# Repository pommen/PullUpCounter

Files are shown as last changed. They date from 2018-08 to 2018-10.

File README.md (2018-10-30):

# PullupCounter
Simple counter that keeps track of how many pullups that has been done in a day and displays it on a double led array display.
Resets every day and only lights up during office hours. Time keeping is done with a DS1307 RTC.
Manually changeable pullups counts with a encoder, to "cheat" or correct the amount of reps that has been done.
Based on a ATMEGA328p MCU (5V16MHZ) running Arduino code.

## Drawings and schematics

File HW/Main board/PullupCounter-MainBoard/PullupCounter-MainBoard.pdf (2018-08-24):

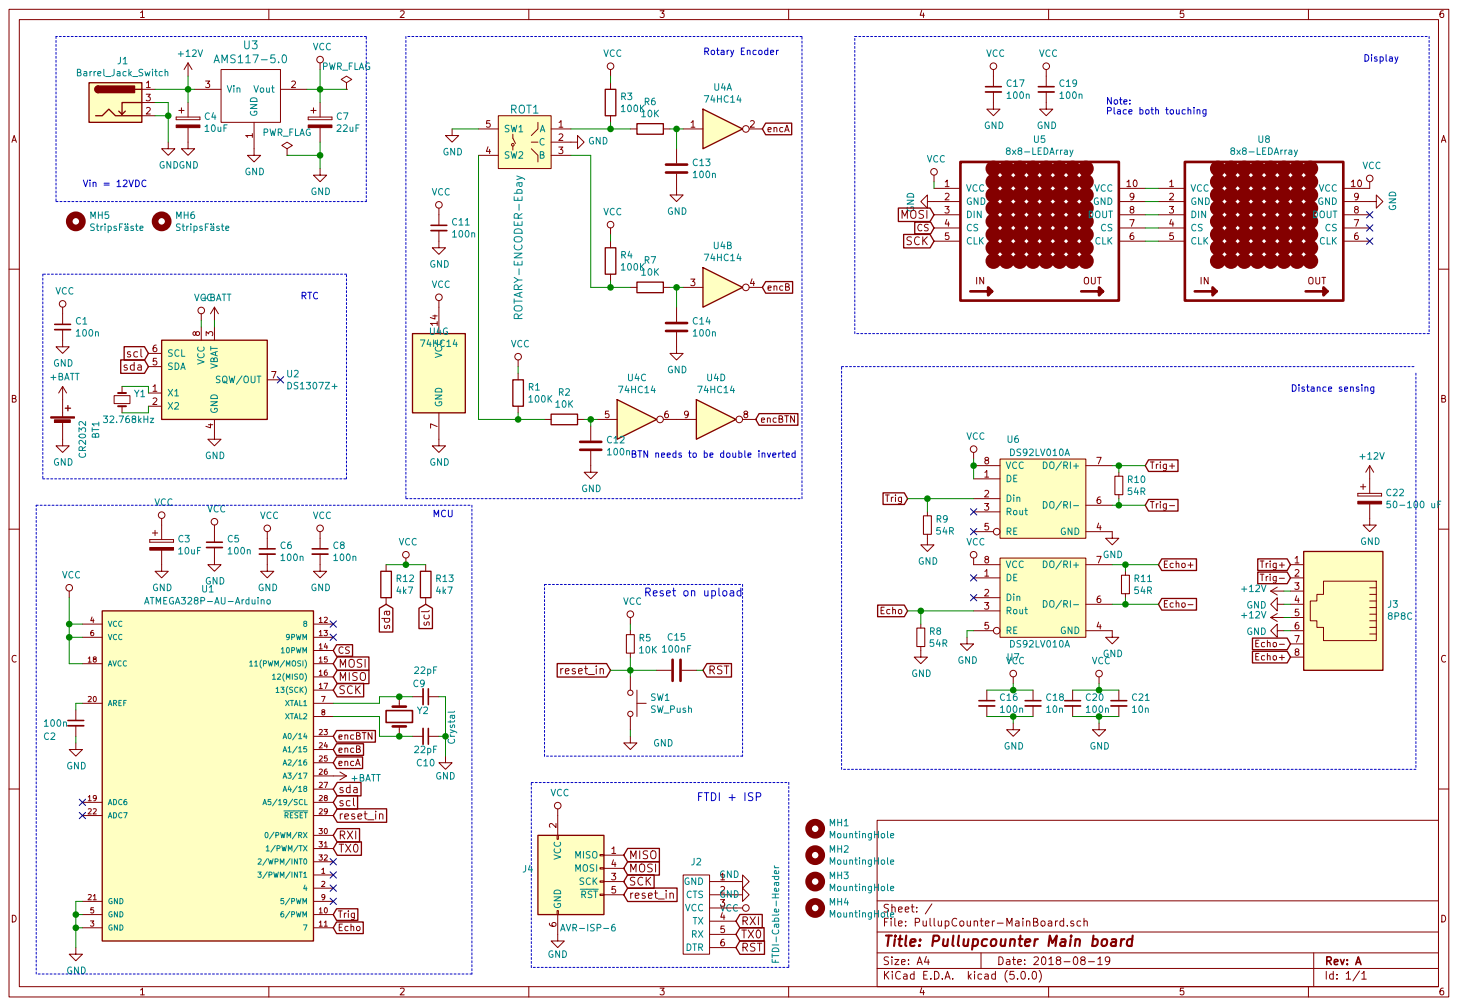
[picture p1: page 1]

4 SDA 5 SCL 6 SQW/OUT 7 VCC

Trig Echo

2 SCK 3 MOSI 4 RST 5 GND

Id: 1/1 Title: Pullupcounter Main board

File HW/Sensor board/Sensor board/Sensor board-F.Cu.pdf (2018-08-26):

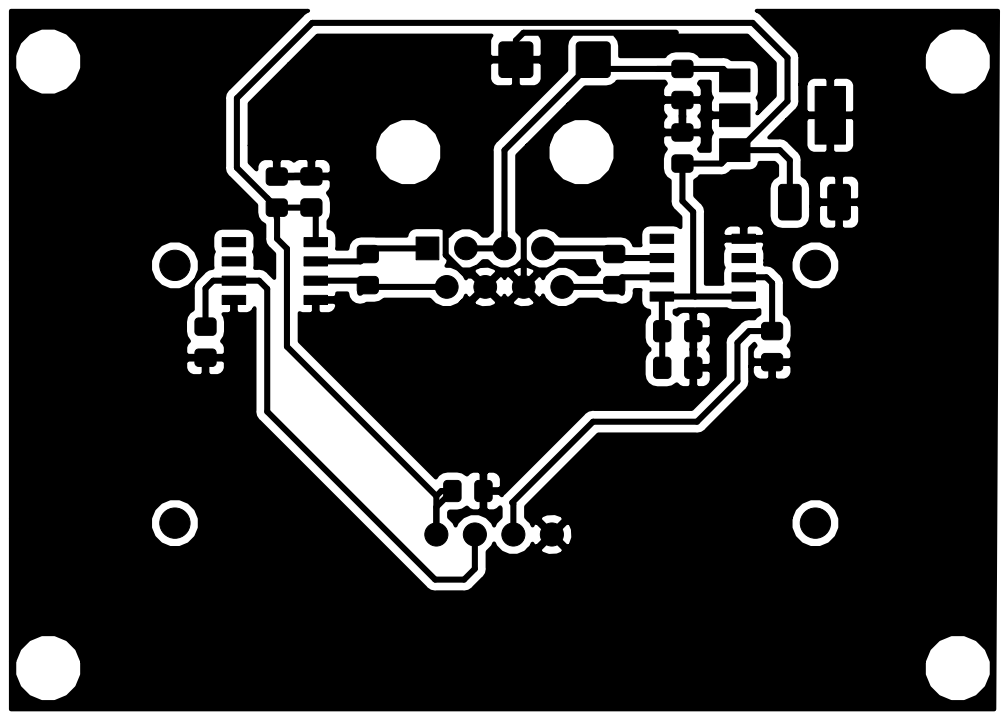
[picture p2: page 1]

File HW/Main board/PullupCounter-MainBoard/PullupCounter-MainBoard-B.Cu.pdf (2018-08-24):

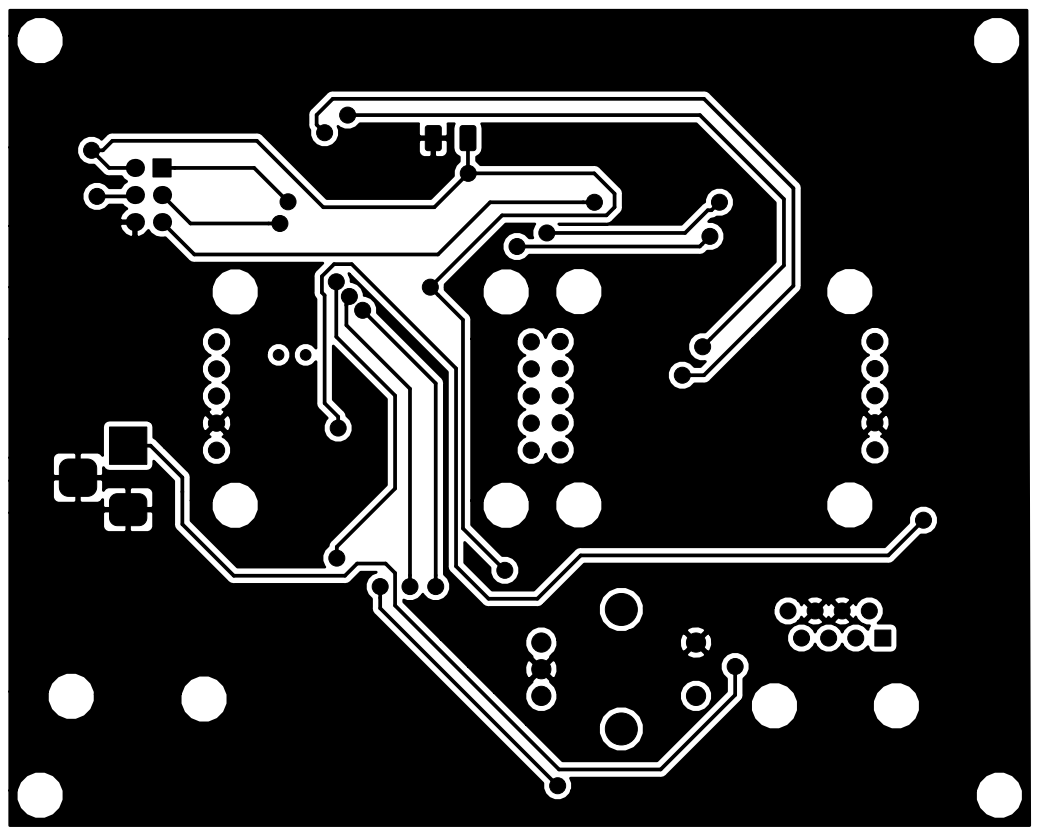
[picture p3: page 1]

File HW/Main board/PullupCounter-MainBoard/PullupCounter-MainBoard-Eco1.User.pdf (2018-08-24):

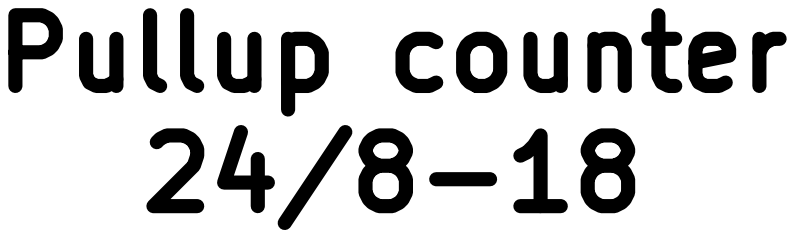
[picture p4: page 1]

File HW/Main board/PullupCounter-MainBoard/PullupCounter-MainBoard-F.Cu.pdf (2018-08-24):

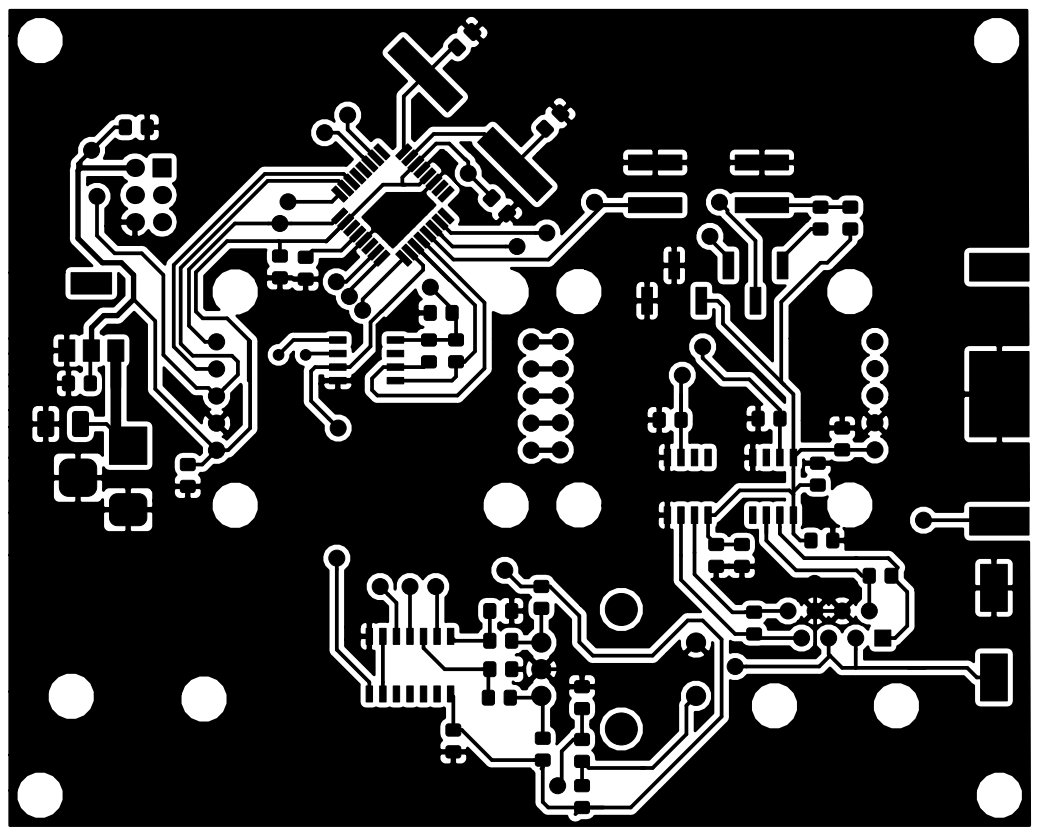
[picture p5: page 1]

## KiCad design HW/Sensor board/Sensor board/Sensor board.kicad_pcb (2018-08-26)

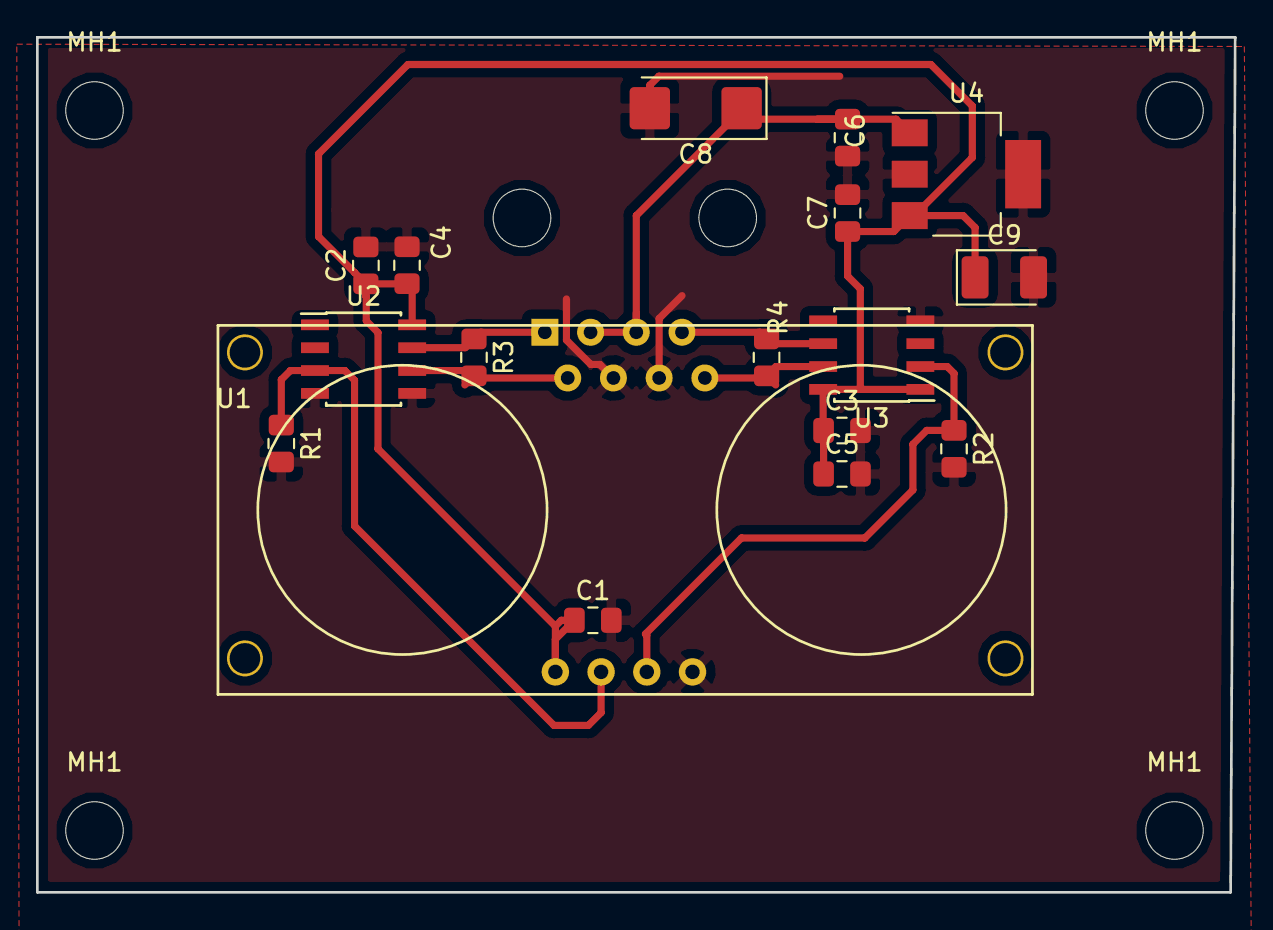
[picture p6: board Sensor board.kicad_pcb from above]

Board: 2 copper layers, 66.5 x 47.5 mm, 22 parts (1 on the bottom side), 9 nets.

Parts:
C1, C2, C3, C6: 100n; C_0805_2012Metric_Pad1.15x1.40mm_HandSolder
C4, C5: 10n; C_0805_2012Metric_Pad1.15x1.40mm_HandSolder
C7: 1u; C_0805_2012Metric_Pad1.15x1.40mm_HandSolder
C8: 15u; CP_EIA-6032-20_AVX-F_Pad2.25x2.35mm_HandSolder
C9: 15u; CP_EIA-3528-12_Kemet-T_Pad1.50x2.35mm_HandSolder
J1: 8P8C; RJ45_Amphenol_54602-x08_Horizontal
MH1, MH1#2, MH1#3, MH1#4: MountingHole; MountingHole_3.2mm_M3_DIN965
R1, R2, R3, R4: 54R; R_0805_2012Metric_Pad1.15x1.40mm_HandSolder
U1: Hc-SR04; HC-SR04
U2, U3: DS92LV010A; SOIC-8_3.9x4.9mm_P1.27mm
U4: LM2937xMP; SOT-223-3_TabPin2

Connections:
+12V: C6.1, C8.1, J1.3, J1.5, U4.1
ECHO: R2.1, U1.3, U3.2
ECHO+: J1.8, R4.1, U3.7
ECHO-: J1.7, R4.2, U3.6
GND: C1.2, C2.2, C3.2, C4.2, C5.2, C6.2, C7.2, C8.2, C9.2, J1.4, J1.6, R1.2, R2.2, U1.4, U2.4, U2.5, U3.4, U4.2
TRIG: R1.1, U1.2, U2.3
TRIG+: J1.1, R3.1, U2.7
TRIG-: J1.2, R3.2, U2.6
VCC: C1.1, C2.1, C3.1, C4.1, C5.1, C7.1, C9.1, U1.1, U2.8, U3.1, U3.8, U4.3

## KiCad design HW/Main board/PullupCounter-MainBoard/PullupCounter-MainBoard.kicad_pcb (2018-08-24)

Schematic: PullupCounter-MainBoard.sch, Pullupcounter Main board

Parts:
BT1: CR2032; BatteryHolder_MPD_BC2003_1x2032
C1, C2, C5, C6, C8, C11, C12, C13, C14, C16, C17, C19, C20: 100n; C_0805_2012Metric_Pad1.15x1.40mm_HandSolder
C3, C4: 10uF; CP_EIA-3528-12_Kemet-T_Pad1.50x2.35mm_HandSolder
C7: 22uF; C_0805_2012Metric_Pad1.15x1.40mm_HandSolder
C9, C10: 22pF; C_0805_2012Metric_Pad1.15x1.40mm_HandSolder
C15: 100nF; C_0805_2012Metric_Pad1.15x1.40mm_HandSolder
C18, C21: 10n; C_0805_2012Metric_Pad1.15x1.40mm_HandSolder
C22: 50-100 uF; CP_Elec_10x10.5
J1: Barrel_Jack_Switch; BarrelJack_Horizontal
J2: FTDI-Cable-Header; PinHeader_1x06_P2.54mm_Vertical_SMD_Pin1Left
J3: 8P8C; RJ45_Amphenol_54602-x08_Horizontal
J4: AVR-ISP-6; PinSocket_2x03_P2.54mm_Vertical
MH1, MH2, MH3, MH4: MountingHole; MountingHole_3.2mm_M3
MH5, MH6: StripsFäste; MountingHole_3.2mm_M3
R1, R3, R4: 100K; R_0805_2012Metric_Pad1.15x1.40mm_HandSolder
R2, R5, R6, R7: 10K; R_0805_2012Metric_Pad1.15x1.40mm_HandSolder
R8, R9, R10, R11: 54R; R_0805_2012Metric_Pad1.15x1.40mm_HandSolder
R12, R13: 4k7; R_0805_2012Metric_Pad1.15x1.40mm_HandSolder
ROT1: ROTARY-ENCODER-Ebay
SW1: SW_Push; PushBTN KSC241G
U1: ATMEGA328P-AU-Arduino; TQFP-32_7x7mm_P0.8mm
U2: DS1307Z+; SOIC-8_3.9x4.9mm_P1.27mm
U3: AMS117-5.0; SOT-223
U4: 74HC14; SOIC-14_3.9x8.7mm_P1.27mm
U5, U8: 8x8-LEDArray; 8x8LEDArray
U6, U7: DS92LV010A; SOIC-8_3.9x4.9mm_P1.27mm
Y1: 32.768kHz; Crystal_AT310_D3.0mm_L10.0mm_Horizontal
Y2: Crystal; Crystal_SMD_HC49-SD_HandSoldering

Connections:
+12V: C4.1, C22.1, J1.1, J3.3, J3.5, U3.3
+BATT: BT1.1, U1.26, U2.3
CS: U1.14, U5.4
Echo: R8.1, U1.11, U7.3
Echo+: J3.8, R11.1, U7.7
Echo-: J3.7, R11.2, U7.6
GND: BT1.2, C1.2, C2.2, C3.2, C4.2, C5.2, C6.2, C7.2, C8.2, C9.1, C10.1, C11.2, C12.2, C13.2, C14.2, C16.2, C17.2, C18.2, C19.2, C20.2, C21.2, C22.2, J1.2, J1.3, J2.1, J2.2, J3.4, J3.6, J4.6, R8.2, R9.2, ROT1.2, ROT1.5, SW1.2, U1.3, U1.5, U1.21, U2.4, U3.1, U4.7 (GND), U5.2, U6.4, U7.4, U7.5, U8.9
MISO: J4.1, U1.16
MOSI: J4.4, U1.15, U5.3
unnamed: C2.1, U1.20
unnamed: C9.2, U1.7, Y2.1
unnamed: C10.2, U1.8, Y2.2
unnamed: C12.1, R2.1, U4.5
unnamed: C13.1, R6.1, U4.1
unnamed: C14.1, R7.1, U4.3
unnamed: R1.2, R2.2, ROT1.4
unnamed: R3.2, R6.2, ROT1.1
unnamed: R4.2, R7.2, ROT1.3
unnamed: U2.1, Y1.1
unnamed: U2.2, Y1.2
unnamed: U4.6, U4.9
unnamed: U5.6, U8.5
unnamed: U5.7, U8.4
unnamed: U5.8, U8.3
unnamed: U5.9, U8.2
unnamed: U5.10, U8.1
RST: C15.1, J2.6
RXI: J2.4, U1.30
SCK: J4.3, U1.17, U5.5
TX0: J2.5, U1.31
Trig: R9.1, U1.10, U6.2
Trig+: J3.1, R10.1, U6.7
Trig-: J3.2, R10.2, U6.6
VCC: C1.1, C3.1, C5.1, C6.1, C7.1, C8.1, C11.1, C16.1, C17.1, C18.1, C19.1, C20.1, C21.1, J2.3, J4.2, R1.1, R3.1, R4.1, R5.1, R12.1, R13.1, U1.4, U1.6, U1.18, U2.8, U3.2, U4.14 (VCC), U5.1, U6.1, U6.8, U7.8, U8.10
encA: U1.25, U4.2
encB: U1.24, U4.4
encBTN: U1.23, U4.8
reset_in: C15.2, J4.5, R5.2, SW1.1, U1.29
scl: R13.2, U1.28, U2.6
sda: R12.2, U1.27, U2.5

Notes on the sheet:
FTDI + ISP
Reset on upload
Note: Place both touching
Display
Distance sensing
Vin = 12VDC
RTC
MCU
Rotary Encoder
BTN needs to be double inverted

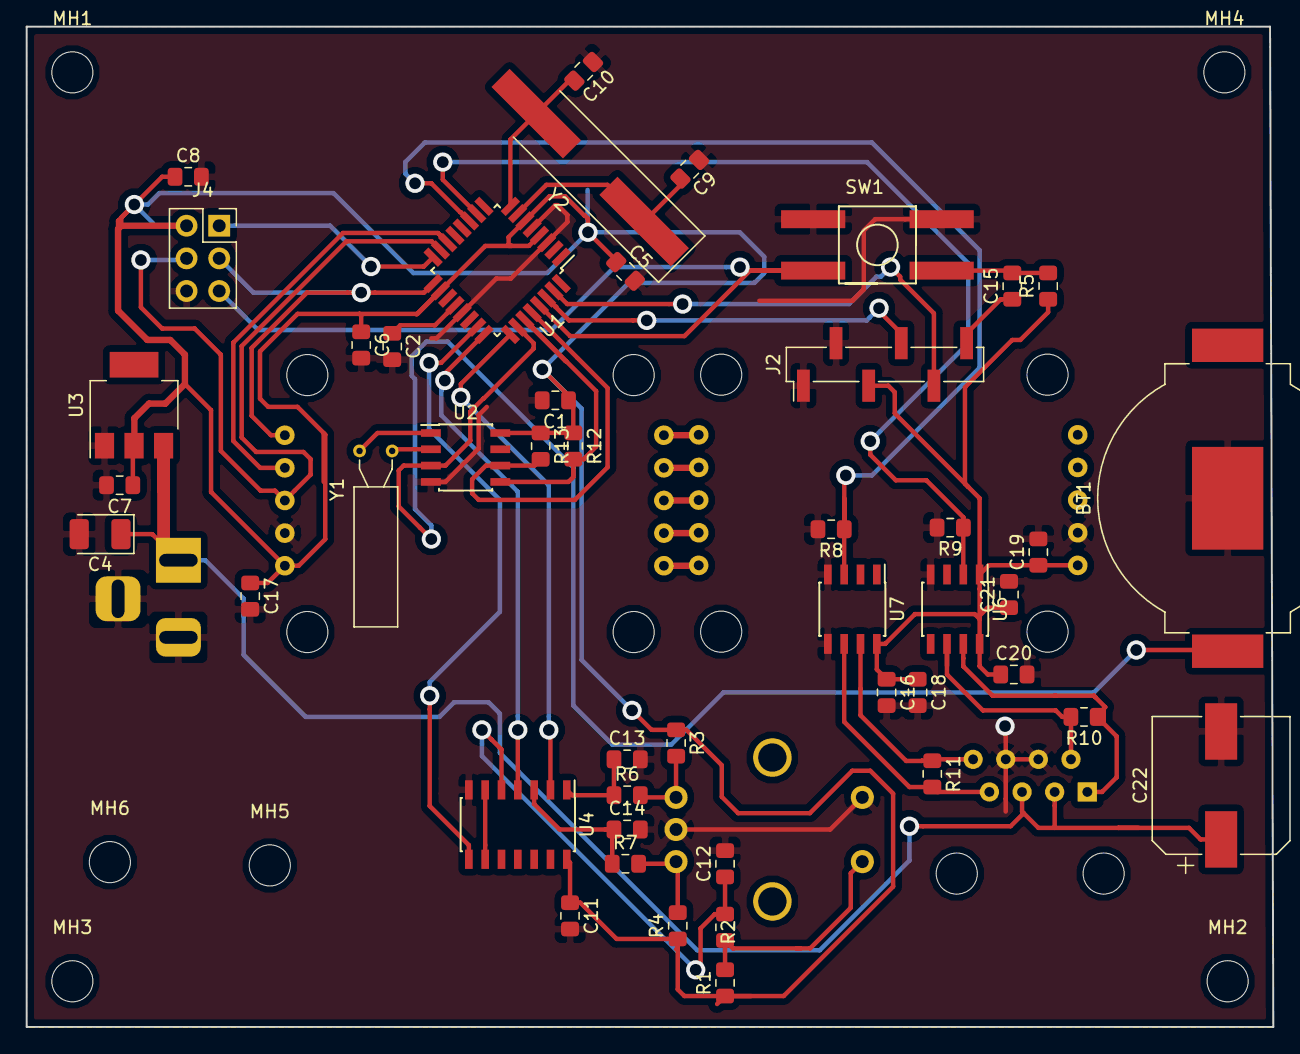
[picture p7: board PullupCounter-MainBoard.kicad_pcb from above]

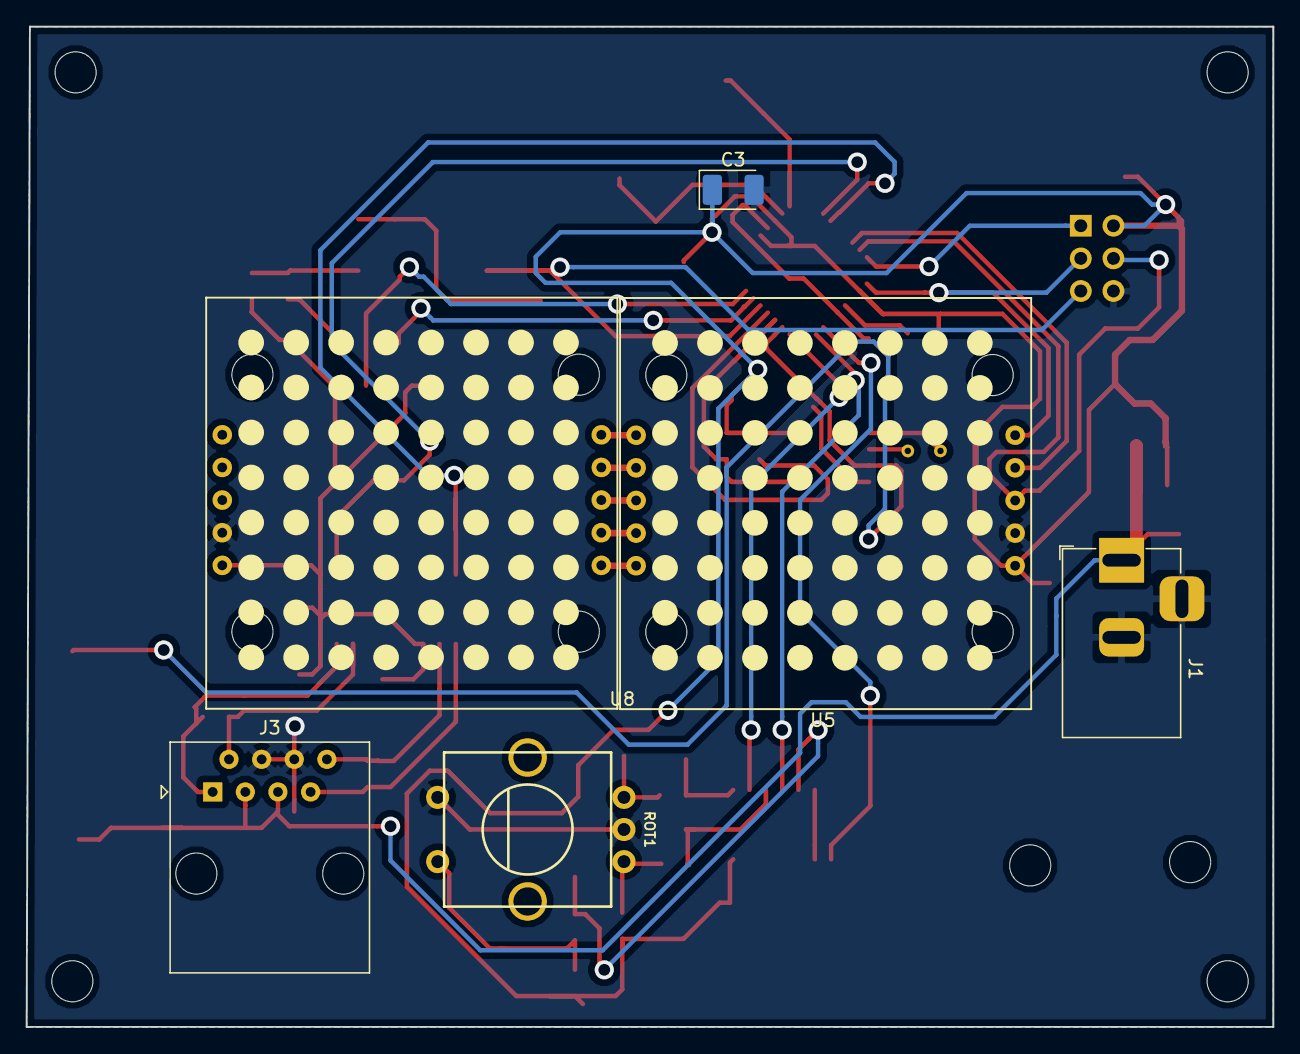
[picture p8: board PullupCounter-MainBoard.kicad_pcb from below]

Board: 2 copper layers, 97.0 x 77.9 mm, 58 parts (6 on the bottom side), 40 nets.

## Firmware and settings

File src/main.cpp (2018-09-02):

/*
Pullup counter till Arnfinn

Maybe to be in 2.0: 

Settings:
      Distance to be a pullup, like a motivational up arrow, or something
      Brightness 0-15
      Time - need more ledarrays to display properly

todo:
Firmware 1.0 done.


*/

#include <Arduino.h>
#include <SPI.h>
#include <bitBangedSPI.h>
#include <MAX7219_Dot_Matrix.h>
#include <ClickEncoder.h>
#include <TimerOne.h>
#include <Wire.h>
#include "RTClib.h"
#include <EEPROM.h>
#include <UltraDistSensor.h>

//**************************

#define DEBUG

//**************************
void setBrightness();
void timerIsr();
void btnstate();
void setCompileTime();
void updateDisplay();
void showTime();
void pulsingHearts();
void Scollingtext();
int16_t oldEncPos, encPos;
uint8_t buttonState;
uint8_t daylightAddr = 0;
bool newNumer = 0;
bool done = 0;
int numPullups = 0;
int oldNumPullups = 0;
char message[] = {};
int lastDay = 0;
int temp = 0;
bool LEDOff = 0;
unsigned long pullUpTime = 0;
unsigned long pullUpHELDTime = 0;
unsigned long hasGoneDownTime = 0;
bool hasGoneDown = 0;
uint16_t rangeUpdateTimer = 0;
uint16_t clockUpdateTimer = 0;
int daylight = 8;
#define pinA A1
#define pinB A2
#define pinSw A0 //switch on enc
#define STEPS 4
char daysOfTheWeek[7][12] = {"Sunday", "Monday", "Tuesday", "Wednesday", "Thursday", "Friday", "Saturday"};
unsigned long lastMoved = 0;
uint8_t MOVE_INTERVAL = 40; // mS
int messageOffset;
int scollingMessageOffset;
const byte chips = 2;
float distanceReading = 0.00;
bool doneWithScolling = 0;

UltraDistSensor mysensor;
RTC_DS1307 rtc;
ClickEncoder encoder(pinA, pinB, pinSw, STEPS);
DateTime now;
// 2 chips (display modules), hardware SPI with load on D10
MAX7219_Dot_Matrix display(chips, 10); // Chips / LOAD

void setup()
{
      Serial.begin(9600);
      display.begin();
      Timer1.initialize(1000);
      Timer1.attachInterrupt(timerIsr);

      encoder.setAccelerationEnabled(false);
      if (!rtc.begin())
      {
            Serial.println("Couldn't find RTC");
      }
      mysensor.attach(6, 7); //Trigger pin , Echo pin
      oldEncPos = 0;
      daylight = EEPROM.get(daylightAddr, daylight);
      Serial.print("Brightness : ");
      Serial.println(daylight);
      if (daylight > 15 || daylight < 0)
      {
            daylight = 8;
      }

      display.setIntensity(daylight);

      setCompileTime();
      //showTime();

      pulsingHearts();
}

void loop()
{
      //update things:

      encPos += encoder.getValue(); //check if the encoder has changed

      if (millis() - clockUpdateTimer >= 30000) //read clock every 30 seconds
      {
            now = rtc.now();
            // Serial.print(now.second(), DEC);					
      }

      if (millis() - rangeUpdateTimer >= 100)
      {
            distanceReading = mysensor.distanceInCm();
            rangeUpdateTimer = millis();
      }

      //***********

   /*    
      Serial.print("Sensor Reading :");
      Serial.print(distanceReading);
      Serial.println(" CM");  */
      

      if (distanceReading > 10.00)
      {
            pullUpTime = millis();
      }
      //else
      // Serial.println(millis() - pullUpTime);

      if (millis() - pullUpTime > 500 && hasGoneDown == 1)
      {
            // pullUpTime = millis();
            Serial.print("Sensor Reading :");
            Serial.print(distanceReading);
            Serial.println(" CM");
            numPullups++;
            hasGoneDown = 0;
      }

      if (distanceReading > 30.00)
      {
            hasGoneDown = 1;
      }

      //has the encoder value changed?
      if (encPos != oldEncPos)
      {
            // Serial.print("Encoder Value: ");
            // Serial.println(encPos);
            int diff = encPos - oldEncPos;
            numPullups = numPullups + diff;
            oldEncPos = encPos;

            //need this here because of some bug... Yuck!
            Serial.print("now.dayOfTheWeek() : ");
            Serial.println(now.dayOfTheWeek());
            Serial.print("lastDay: ");
            Serial.println(lastDay);
      }

      //never under 0 pullups!
      if (numPullups < 0)
      {
            numPullups = 0;
            oldNumPullups = 0;
      }

      //Is there a new number to display?
      if (numPullups != oldNumPullups)
      {
            newNumer = 1;
            oldNumPullups = numPullups;
            done = 0;
            Serial.println(numPullups);
      }
      else
            newNumer = 0;

      // update display if time is time to
      if (millis() - lastMoved >= MOVE_INTERVAL)
      {
            updateDisplay();
            lastMoved = millis();
      }

      //Check the encoder button state (with state machine)
      // btnstate();

      if (lastDay != now.dayOfTheWeek())
      {
            lastDay = now.dayOfTheWeek();
            numPullups = 0;
            oldNumPullups = 0;
            temp = lastDay;
            Serial.println("Resetting due to New day!");
            Serial.print("now.dayOfTheWeek() : ");
            Serial.println(now.dayOfTheWeek());
            Serial.print("lastDay: ");
            Serial.println(lastDay);
      }

      //Turn off the LED's at 'out of office hours'
      if (!LEDOff)
      {
            if (now.hour() < 6 || now.hour() > 18)
            {

#ifndef DEBUG

                  display.end();
                  LEDOff = 1;
#else
                  display.setIntensity(0);
                  LEDOff = 1;

#endif // DEBUG
            }
            else
            {
                  display.setIntensity(daylight);
                  LEDOff = 0;
            }
      }

      btnstate(); //have we pressed the encoder button?

} // end of loop

void updateDisplay()
{
      itoa(numPullups, message, 10); //int to string

      if (done)
      {
            display.sendString(message);
      }
      else
      {
           /*  Serial.print("messageOffset: ");

            Serial.println(messageOffset); */
            display.sendSmooth(message, messageOffset);
            // next time show one pixel onwards
            if (messageOffset++ >= (int)(strlen(message) * 8))
            { //if we have run though the display
                  done = 1;
                  messageOffset = -chips * 8;
            }
      }
}

void timerIsr()
{
      encoder.service();
}

void btnstate()
{

      buttonState = encoder.getButton();

      if (buttonState != 0)
      {
            Serial.print("Button: ");
            Serial.println(buttonState);
            switch (buttonState)
            {
            case ClickEncoder::Open: //0
                  break;

            case ClickEncoder::Closed: //1
                  break;

            case ClickEncoder::Pressed: //2

                  break;

            case ClickEncoder::Held: //3
                  setBrightness();

                  break;

            case ClickEncoder::Released: //4
                  break;

            case ClickEncoder::Clicked: //5
                  numPullups = 0;
                  break;

            case ClickEncoder::DoubleClicked: //6

                  break;
            }
      }
      // do other stuff here
}

void setCompileTime()
{
      if (!rtc.isrunning())
      {
            Serial.println("RTC is NOT running!");
      rtc.adjust(DateTime(F(__DATE__), F(__TIME__)));
      Serial.print(" Setting RTC to compile time: ");
      }
if(Serial)       rtc.adjust(DateTime(F(__DATE__), F(__TIME__)));

      // following line sets the RTC to the date & time this sketch was compiled
      // This line sets the RTC with an explicit date & time, for example to set
      // January 21, 2014 at 3am you would call:
      // rtc.adjust(DateTime(2014, 1, 21, 3, 0, 0));

      now = rtc.now();
      lastDay = now.day();
      showTime();
}

void showTime()
{
      Serial.print("Compile time: ");
      Serial.print(F(__DATE__));
      Serial.print(" : ");
      Serial.print(F(__TIME__));
      Serial.println();
      Serial.println();
      Serial.println("Current Time: ");

      now = rtc.now();
      Serial.print(now.year(), DEC);
      Serial.print('/');
      Serial.print(now.month(), DEC);
      Serial.print('/');
      Serial.print(now.day(), DEC);
      Serial.print(" (");
      Serial.print(daysOfTheWeek[now.dayOfTheWeek()]);
      Serial.print(") ");
      Serial.print(now.hour(), DEC);
      Serial.print(':');
      Serial.print(now.minute(), DEC);
      Serial.print(':');
      Serial.print(now.second(), DEC);
      Serial.println();

      Serial.println();
      if (!rtc.isrunning())
      {
            Serial.println("RTC is NOT running!");
      }
      else
            Serial.println("RTC is running!");
      Serial.println();
}

void pulsingHearts()
{
      display.sendChar(0, 03); //sends a heart (see the font png. for code)  (Witch display, witch char)
      display.sendChar(1, 03);
      int bootup = millis();
      int i = 0;
      bool countDown = 0;
      while (millis() - bootup < 4000)
      {
            display.setIntensity(i);
            delay(35);

            if (countDown)
            {
                  i--;
            }
            else
                  i++;

            if (i == 15)
                  countDown = 1;
            if (i == 0)
                  countDown = 0;
      }
}

void setBrightness()
{
      unsigned long lastMovedScolling = 0;

      while (buttonState != 5)
      {
            daylight += encoder.getValue();
            if (daylight < 0)
                  daylight = 0;
            else if (daylight > 15)
                  daylight = 15;

            buttonState = encoder.getButton();
            display.setIntensity(daylight);
            if (millis() - lastMovedScolling >= MOVE_INTERVAL)
            {
                  Scollingtext();
                  lastMovedScolling = millis();
            }
      }
      EEPROM.put(daylightAddr, daylight);
}
void Scollingtext()
{
      char printtodisp[] = {"Set brightness"};
      if (doneWithScolling)
      {
            doneWithScolling = 0;
      }
      else
      {

            display.sendSmooth(printtodisp, scollingMessageOffset);
            // next time show one pixel onwards
            if (scollingMessageOffset++ >= (int)(strlen(printtodisp) * 8))
            { //if we have run though the display
                  doneWithScolling = 1;
                  scollingMessageOffset = -chips * 8;
            }
      }
}

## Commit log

2018-08-19 soon done
    [PullupCounter-MainBoard.sch]
2018-08-19 Schematic and layout
    [PullupCounter-MainBoard.kicad_pcb, PullupCounter-MainBoard.sch]
2018-08-19 Layout started
    Need to committo a board size and hole pattern
    [PullupCounter-MainBoard.kicad_pcb, PullupCounter-MainBoard.sch]
2018-08-24 Mainboard
    Version 1 of mainboard done
    [PullupCounter-MainBoard.kicad_pcb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]
2018-08-26 SensorBoard schematic and layout v1
    [Sensor board.kicad_pcb, Sensor board.sch, _saved_Sensor board.sch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]
